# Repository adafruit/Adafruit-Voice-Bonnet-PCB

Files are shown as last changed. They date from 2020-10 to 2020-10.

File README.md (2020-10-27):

## Adafruit Voice Bonnet PCB

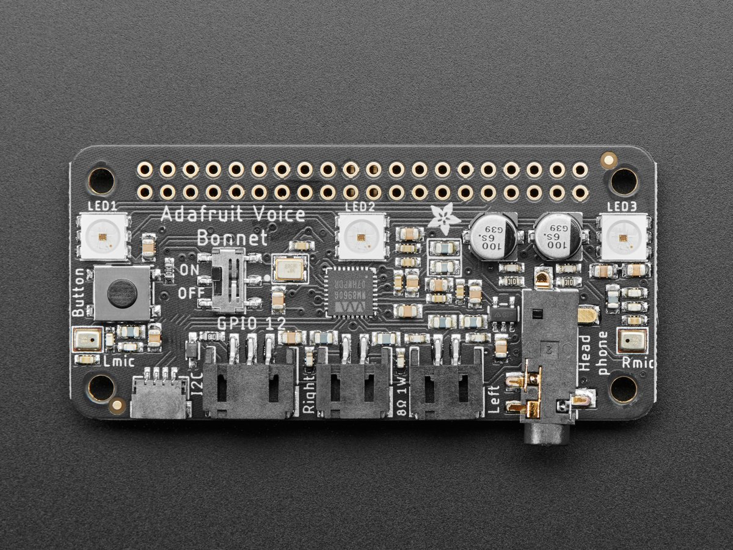
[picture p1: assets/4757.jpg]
<a href="http://www.adafruit.com/products/4757"><br/>
Click here to purchase one from the Adafruit shop</a>

PCB files for the Adafruit Voice Bonnet.

Format is EagleCAD schematic and board layout
* https://www.adafruit.com/product/4757

### Description

Your Raspberry Pi computer is like an electronic brain - and with the Adafruit Voice Bonnet you can give it a mouth and ears as well! Featuring two microphones and two 1 Watt speaker outputs using a high quality I2S codec, this Pi add-on will work with any Raspberry Pi with a 2x20 connector - from the Pi Zero up to the Pi 4 and beyond (basically all but the very first ones made).

The on-board WM8960 codec uses I2S digital audio for great quality recording and playback - so it sounds a lot better than the headphone jack on the Pi (or the no-headphone jack on a Pi Zero). We put ferrite beads and filter capacitors on every input and output to get the best possible performance, and all at a great price.

We specifically designed this bonnet for use with making machine learning projects such as DIY voice assistants - for example see this guide on creating a DIY Google Assistant. But you could do various voice activated or voice recognition projects. With two microphones, basic voice position can be detected as well.

* WM8960 codec uses I2S digital audio for both input and output
* On/Off privacy switch to deactivate audio so you know it can't be recording.
* Two analog microphone inputs (left and right)
* Two 1W speaker outputs
* 3.5mm stereo headphone or line-out audio
* Plugs into any Raspberry Pi with 2x20 headers

With the extra space on the PCB we also added some bonus extras!

* Push button - Use to change modes, activate the voice assistant, anything you like!
* Three DotStar RGB LEDs - add LED feedback or make a rainbow light show
* STEMMA QT connector - plug in any of our I2C sensors, OLEDs, or accessories.
* 3 Pin JST STEMMA connector - for larger accessories, like NeoPixels, a relay or servo

No assembly required! Simply pop it onto your Pi and install the microphone/speaker card using our installer script. Your Pi will then have stereo input and output for use in any software - they appear as any other speaker/mic would. Play music or record audio with ease. For audio input, the two microphones are built into the Bonnet. For audio output, you can either use the Line-out/Headphone 3.5mm stereo jack or you can plug in one or two of our enclosed speakers. For DIY speakers, solder any 1W+ speaker to one of these JST 2-PH cables. If you'd like to stack another HAT or bonnet on top, use a 2x20 stacking header to feed through the 2x20 connector.

### License

Adafruit invests time and resources providing this open source design, please support Adafruit and open-source hardware by purchasing products from [Adafruit](https://www.adafruit.com)!

Designed by Limor Fried/Ladyada for Adafruit Industries.

Creative Commons Attribution/Share-Alike, all text above must be included in any redistribution.
See license.txt for additional details.

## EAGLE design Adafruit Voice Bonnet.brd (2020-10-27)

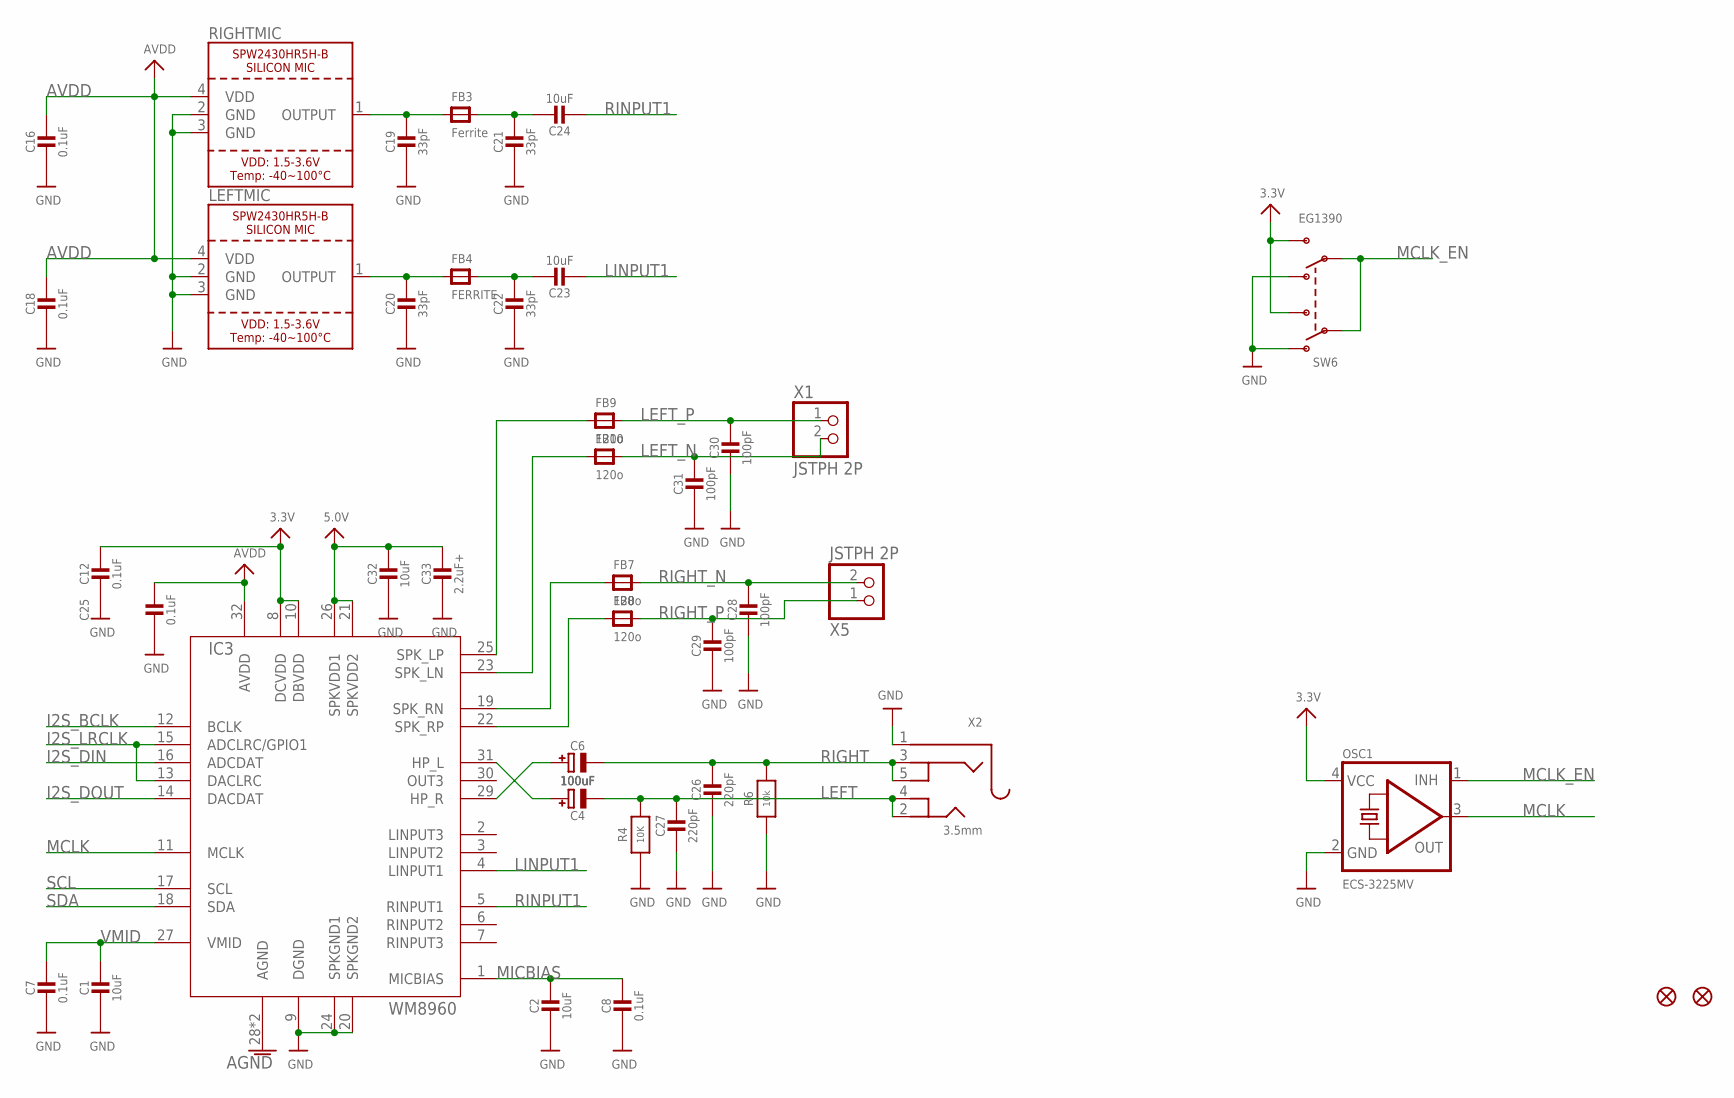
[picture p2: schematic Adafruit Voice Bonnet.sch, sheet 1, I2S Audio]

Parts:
C1, C2, C23, C24, C32: 10uF; 0805-NO
C4, C6: 100uF; PANASONIC_C
C7, C8, C12, C16, C18, C25: 0.1uF; 0603-NO
C19, C20, C21, C22: 33pF; 0603-NO
C26, C27: 220pF; 0603-NO
C28, C29, C30, C31: 100pF; 0603-NO
C33: 2.2uF+; 0805-NO
FB3: Ferrite; 0805-NO
FB4: FERRITE; 0805-NO
FB7, FB8, FB9, FB10: 120o; 0805-NO
FID1, FID2: FIDUCIAL_1MM
IC3: WM8960; QFN32_5MM
LEFTMIC: SPW2430HR5H-B
OSC1: ECS-3225MV; OSC_3.2X2.5MM
R4: 10K; 0603-NO
R6: 10k; 0603-NO
RIGHTMIC: SPW2430HR5H-B
SW6: EG1390
X1, X5: JSTPH 2P; JSTPH2
X2: 3.5mm; 4UCONN_19269

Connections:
3.3V: C12.1, IC3.8 (DCVDD), IC3.10 (DBVDD), OSC1.4 (VCC), SW6.S1, SW6.S2; also elsewhere on the board
5.0V: C32.1, C33.1, IC3.21 (SPKVDD2), IC3.26 (SPKVDD1); also elsewhere on the board
AGND: IC3.28 (AGND), IC3.33 (AGND); also elsewhere on the board
AVDD: C16.1, C18.1, C25.1, IC3.32 (AVDD), LEFTMIC.4 (VDD), RIGHTMIC.4 (VDD); also elsewhere on the board
GND: C1.2, C2.2, C7.2, C8.2, C12.2, C16.2, C18.2, C19.2, C20.2, C21.2, C22.2, C25.2, C26.2, C27.2, C28.2, C29.2, C30.2, C31.2, C32.2, C33.2, IC3.9 (DGND), IC3.20 (SPKGND2), IC3.24 (SPKGND1), LEFTMIC.2 (GND), LEFTMIC.3 (GND), OSC1.2 (GND), R4.1, R6.1, RIGHTMIC.2 (GND), RIGHTMIC.3 (GND), SW6.O1, SW6.O2, X2.1; also elsewhere on the board
I2S_BCLK: IC3.12 (BCLK); also elsewhere on the board
I2S_DIN: IC3.16 (ADCDAT); also elsewhere on the board
I2S_DOUT: IC3.14 (DACDAT); also elsewhere on the board
I2S_LRCLK: IC3.13 (DACLRC), IC3.15 (ADCLRC/GPIO1); also elsewhere on the board
LEFT: C4.-, C27.1, R4.2, X2.2, X2.4
LEFT_N: C31.1, FB10.2, X1.2
LEFT_P: C30.1, FB9.2, X1.1
LINPUT1: C23.2, IC3.4 (LINPUT1)
MCLK: IC3.11 (MCLK), OSC1.3 (OUT)
MCLK_EN: OSC1.1 (INH), SW6.P1, SW6.P2
MICBIAS: C2.1, C8.1, IC3.1 (MICBIAS)
unnamed: FB7.1, IC3.19 (SPK_RN)
unnamed: FB8.1, IC3.22 (SPK_RP)
unnamed: C6.+, IC3.29 (HP_R)
unnamed: C4.+, IC3.31 (HP_L)
unnamed: C19.1, FB3.1, RIGHTMIC.1 (OUTPUT)
unnamed: C20.1, FB4.1, LEFTMIC.1 (OUTPUT)
unnamed: C21.1, C24.1, FB3.2
unnamed: C22.1, C23.1, FB4.2
unnamed: FB9.1, IC3.25 (SPK_LP)
unnamed: FB10.1, IC3.23 (SPK_LN)
RIGHT: C6.-, C26.1, R6.2, X2.3, X2.5
RIGHT_N: C28.1, FB7.2, X5.2
RIGHT_P: C29.1, FB8.2, X5.1
RINPUT1: C24.2, IC3.5 (RINPUT1)
SCL: IC3.17 (SCL); also elsewhere on the board
SDA: IC3.18 (SDA); also elsewhere on the board
VMID: C1.1, C7.1, IC3.27 (VMID)

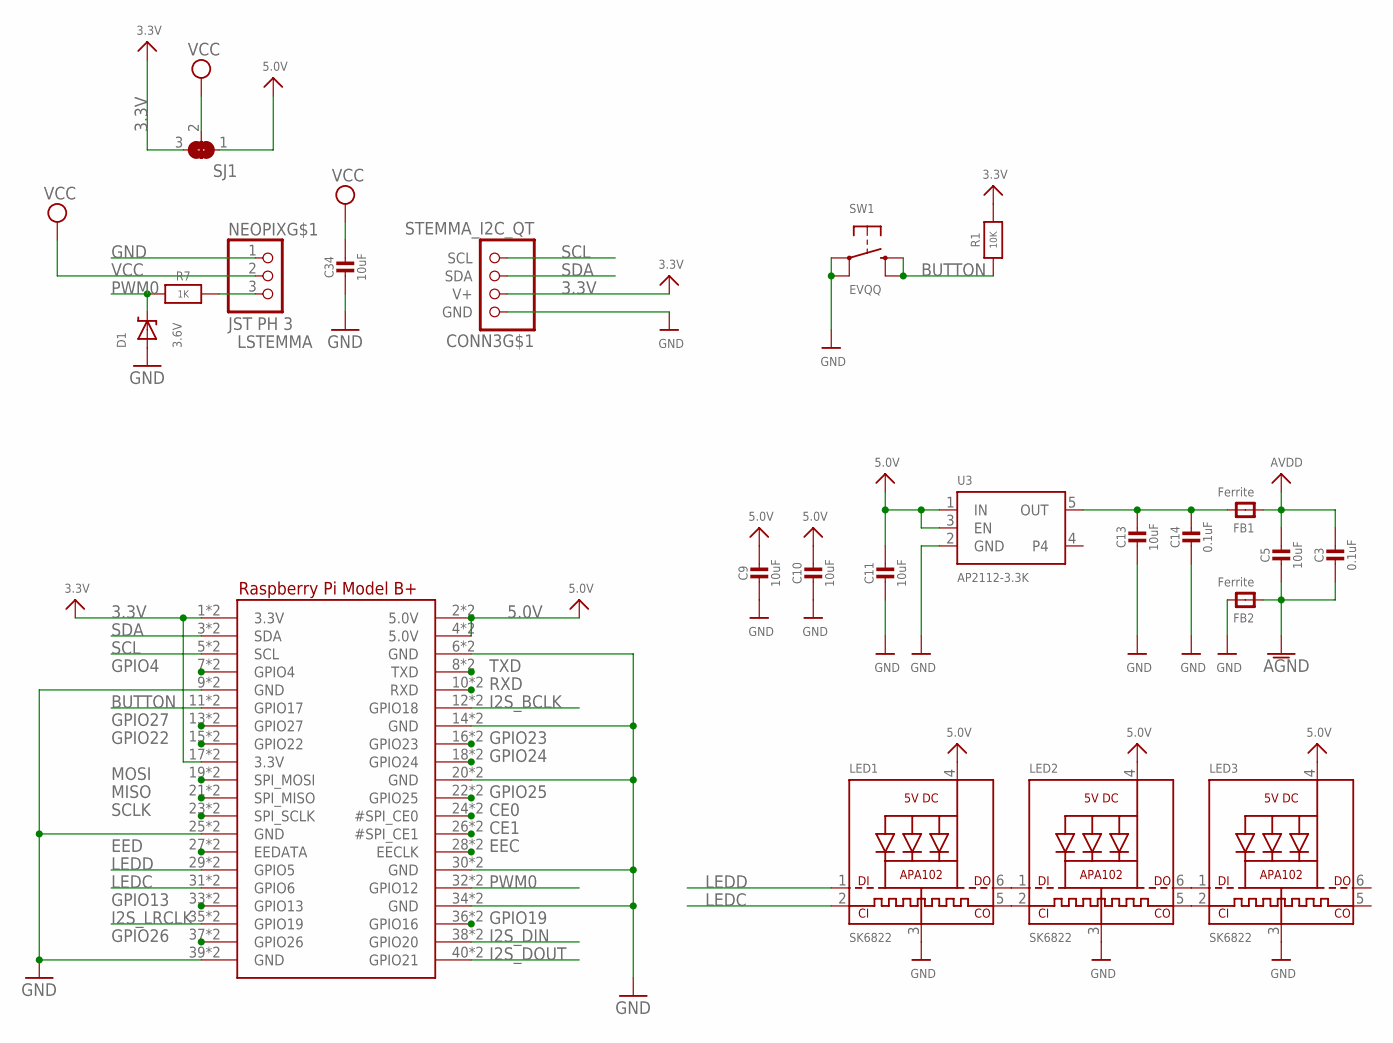
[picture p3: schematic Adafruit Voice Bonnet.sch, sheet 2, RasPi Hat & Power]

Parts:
C3, C14: 0.1uF; 0603-NO
C5, C9, C10, C11, C13, C34: 10uF; 0805-NO
CONN3: STEMMA_I2C_QT; JST_SH4
D1: 3.6V; SOD-323
FB1, FB2: Ferrite; 0805
LED1, LED2, LED3: SK6822; APA102
NEOPIX: JST PH 3; JSTPH3
R1: 10K; 0603-NO
R7: 1K; 0603-NO
RPI1: RASPBERRYPI_BPLUS_BONNET_THMSMT; PI_BONNET_THMSMT
SJ1: SOLDERJUMPER_2WAY; SOLDERJUMPER_2WAY_OPEN_NOPASTE
SW1: EVQQ; EVQ-Q2_SMALLER
U3: AP2112-3.3K; SOT23-5

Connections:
3.3V: CONN3.2 (V+), R1.2, RPI1.1 (3.3V), RPI1.17 (3.3V), RPI1.S1 (3.3V), RPI1.S17 (3.3V), SJ1.3; also elsewhere on the board
5.0V: C9.1, C10.1, C11.1, LED1.4 (VDD), LED2.4 (VDD), LED3.4 (VDD), RPI1.2 (5.0V), RPI1.4 (5.0V), RPI1.S2 (5.0V), RPI1.S4 (5.0V), SJ1.1, U3.1 (IN), U3.3 (EN); also elsewhere on the board
AGND: C3.2, C5.2, FB2.1; also elsewhere on the board
AVDD: C3.1, C5.1, FB1.1; also elsewhere on the board
BUTTON: R1.1, RPI1.11 (GPIO17), RPI1.S11 (GPIO17), SW1.B (S), SW1.B' (S1)
CE0: RPI1.24 (#SPI_CE0), RPI1.S24 (#SPI_CE0)
CE1: RPI1.26 (#SPI_CE1), RPI1.S26 (#SPI_CE1)
EEC: RPI1.28 (EECLK), RPI1.S28 (EECLK)
EED: RPI1.27 (EEDATA), RPI1.S27 (EEDATA)
GND: C9.2, C10.2, C11.2, C13.2, C14.2, C34.2, CONN3.1 (GND), D1.A, FB2.2, LED1.3 (GND), LED2.3 (GND), LED3.3 (GND), NEOPIX.1, RPI1.6 (GND), RPI1.9 (GND), RPI1.14 (GND), RPI1.20 (GND), RPI1.25 (GND), RPI1.30 (GND), RPI1.34 (GND), RPI1.39 (GND), RPI1.S6 (GND), RPI1.S9 (GND), RPI1.S14 (GND), RPI1.S20 (GND), RPI1.S25 (GND), RPI1.S30 (GND), RPI1.S34 (GND), RPI1.S39 (GND), SW1.A, SW1.A' (P1), U3.2 (GND); also elsewhere on the board
GPIO4: RPI1.7 (GPIO4), RPI1.S7 (GPIO4)
GPIO13: RPI1.33 (GPIO13), RPI1.S33 (GPIO13)
GPIO19: RPI1.36 (GPIO16), RPI1.S36 (GPIO16)
GPIO22: RPI1.15 (GPIO22), RPI1.S15 (GPIO22)
GPIO23: RPI1.16 (GPIO23), RPI1.S16 (GPIO23)
GPIO24: RPI1.18 (GPIO24), RPI1.S18 (GPIO24)
GPIO25: RPI1.22 (GPIO25), RPI1.S22 (GPIO25)
GPIO26: RPI1.37 (GPIO26), RPI1.S37 (GPIO26)
GPIO27: RPI1.13 (GPIO27), RPI1.S13 (GPIO27)
I2S_BCLK: RPI1.12 (GPIO18), RPI1.S12 (GPIO18); also elsewhere on the board
I2S_DIN: RPI1.38 (GPIO20), RPI1.S38 (GPIO20); also elsewhere on the board
I2S_DOUT: RPI1.40 (GPIO21), RPI1.S40 (GPIO21); also elsewhere on the board
I2S_LRCLK: RPI1.35 (GPIO19), RPI1.S35 (GPIO19); also elsewhere on the board
LEDC: LED1.2 (CKI), RPI1.31 (GPIO6), RPI1.S31 (GPIO6)
LEDD: LED1.1 (DI), RPI1.29 (GPIO5), RPI1.S29 (GPIO5)
LSTEMMA: NEOPIX.3, R7.1
MISO: RPI1.21 (SPI_MISO), RPI1.S21 (SPI_MISO)
MOSI: RPI1.19 (SPI_MOSI), RPI1.S19 (SPI_MOSI)
unnamed: LED1.6 (DO), LED2.1 (DI)
unnamed: LED1.5 (CKO), LED2.2 (CKI)
unnamed: LED2.6 (DO), LED3.1 (DI)
unnamed: LED2.5 (CKO), LED3.2 (CKI)
OUT: C13.1, C14.1, FB1.2, U3.5 (OUT)
PWM0: D1.C, R7.2, RPI1.32 (GPIO12), RPI1.S32 (GPIO12)
RXD: RPI1.10 (RXD), RPI1.S10 (RXD)
SCL: CONN3.4 (SCL), RPI1.5 (SCL), RPI1.S5 (SCL); also elsewhere on the board
SCLK: RPI1.23 (SPI_SCLK), RPI1.S23 (SPI_SCLK)
SDA: CONN3.3 (SDA), RPI1.3 (SDA), RPI1.S3 (SDA); also elsewhere on the board
TXD: RPI1.8 (TXD), RPI1.S8 (TXD)
VCC: C34.1, NEOPIX.2, SJ1.2

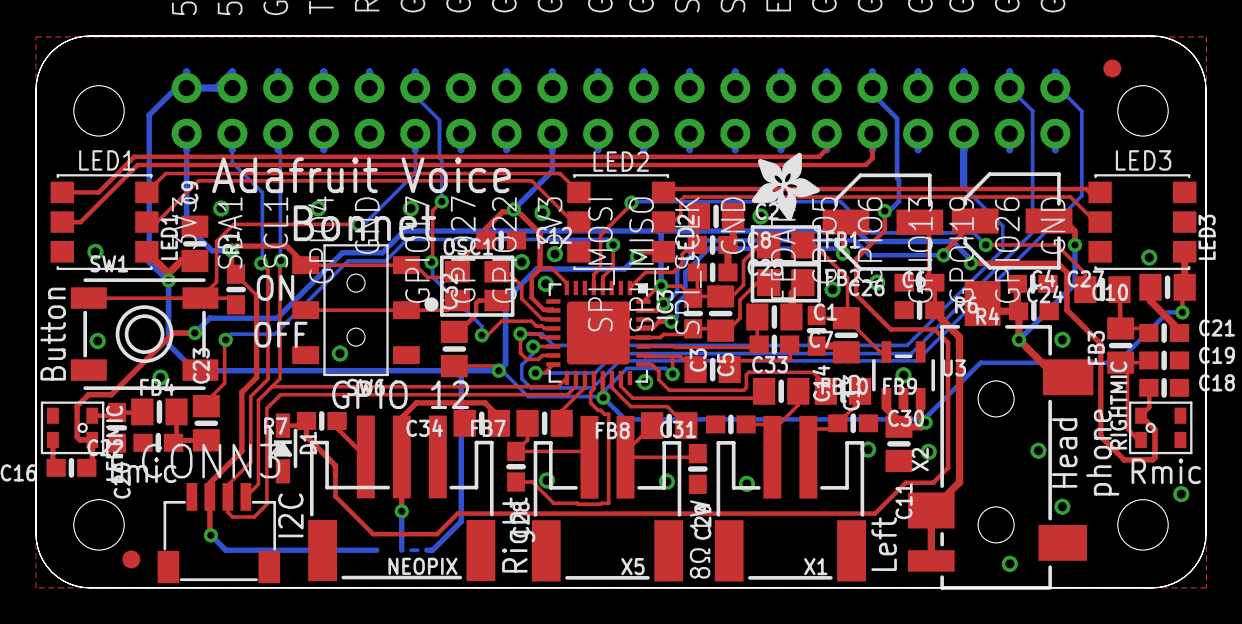
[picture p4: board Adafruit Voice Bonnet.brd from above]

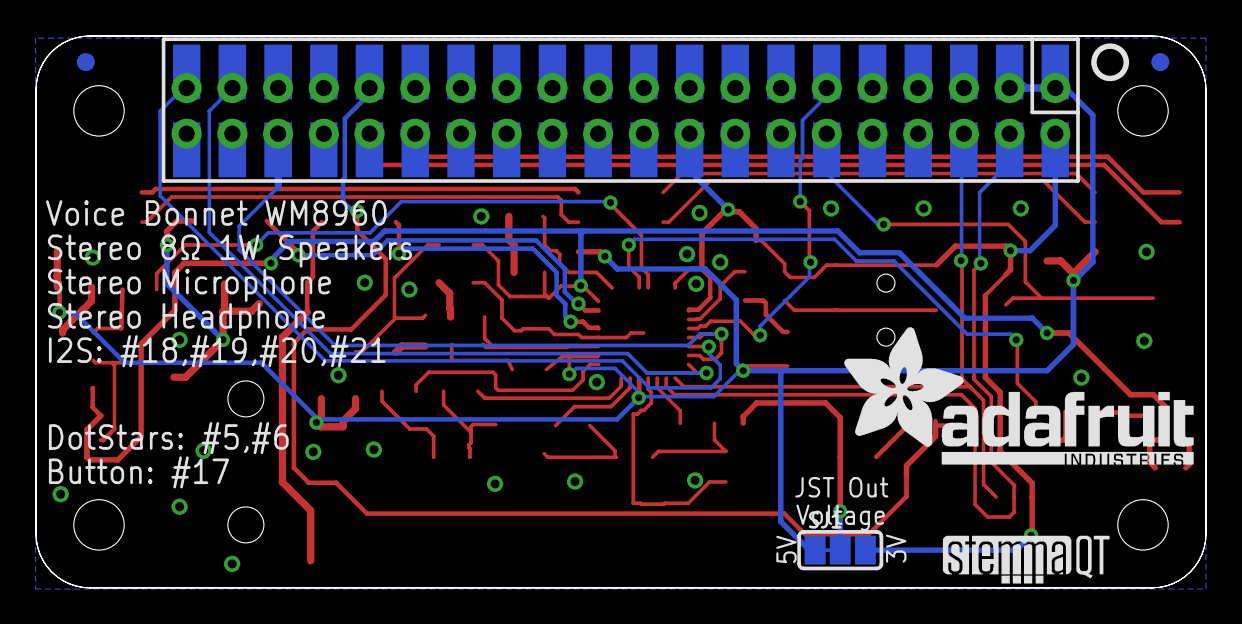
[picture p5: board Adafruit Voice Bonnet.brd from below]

Board: 2 copper layers, 65.0 x 30.7 mm, 69 parts (5 on the bottom side), 62 nets.

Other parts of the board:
U$11: PCBFEAT-REV-040
U$12: STEMMAQT
U$15: ADAFRUIT_3.5MM
U$16: ADAFRUIT_TEXT_20MM
U$79: BRAINPAD_1IN

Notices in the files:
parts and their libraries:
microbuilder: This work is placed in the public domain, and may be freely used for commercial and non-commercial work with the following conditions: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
